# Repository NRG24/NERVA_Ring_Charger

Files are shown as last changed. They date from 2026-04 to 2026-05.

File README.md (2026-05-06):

# NERVA_Ring_Charger
So this is the charger for the NERVA Ring, I suggest taking a look: https://github.com/NRG24/NERVA_Ring This is a portable, magnetic charging case for the ring using a strategic power path management system. There is a 100mAh battery, which balances size with capacity. There are also magnets perfectly spaced to allow for a snapping mechanism. 
The real magic is actually hidden, however. There is an extremely low profile 4mm magnetic pogo connector on the NERVA Ring's PCB that allows for secure connectivity. It was very difficult to find. 
There is a print-in-place hinge for the box to open and close with 0.25mm tolerances. 
The circuit works by splitting the 5V input voltage (USBC) and having one half charge the onboard 100mAh LiPo. Then, it goes through a boost converter to 4.6 volts which is precisely and strategically under 5V. Because of the two Schottky diode OR-ing system, the 5V (top half) current will take priority and go to charge the 22mAh ring battery. When the case is not plugged in, the boost converter will provide just enough voltage and current to charge the ring battery as well.
Screenshot 2026-04-29 at 3 23 45 PM
Screenshot 2026-04-29 at 3 45 39 PM
Screenshot 2026-04-29 at 10 37 57 PM
Screenshot 2026-05-06 at 9 14 18 AM

Screenshot 2026-04-29 at 10 38 20 PM

https://github.com/user-attachments/assets/c79a6dce-659e-46af-84e8-e46c985744b7

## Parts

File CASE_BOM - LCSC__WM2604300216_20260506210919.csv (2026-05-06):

LCSC Part Number | Manufacture Part Number | Manufacturer | Customer NO. | Package | Description | RoHS | Quantity | Unit Price($) | Ext.Price($) | Estimated lead time (business days) | Updated lead time | Date Code / Lot No.
C191023 | 1N5819WS | Guangdong Hottech |  | SOD-323 | Diode 40V 1A Surface Mount SOD-323 | YES | 50 | 0.0111 | 0.56
C424093 | MCP73831T-2ACI/OT | MICROCHIP |  | SOT-23-5 | 3.75V~6V Lithium Battery 1 550mA SOT-23-5 Battery Chargers ICs RoHS | YES | 10 | 0.5988 | 5.99
C7433013 | DY-5173URD/SN-A3(EL)(HF) | TONYU |  | DIP | Red 631nm LED Indication - Discrete 1.8V~2.4V DIP | YES | 10 | 0.0545 | 0.55
C478087 | MCP1640BT-I/CHY | MICROCHIP |  | SOT-23-6 | 500kHz Boost Adjustable 2V~5.5V 350mA SOT-23-6 Voltage Regulators - DC DC Switching Regulators RoHS | YES | 10 | 0.6572 | 6.57
C42400252 | HYCW498-USBC16-735B | HOAUC |  | SMD | USB-C (USB TYPE-C) Receptacle Connector 16 Position Surface Mount, Right Angle | YES | 10 | 0.0481 | 0.48
C1779 | CL21A475KAQNNNE | Samsung Electro-Mechanics |  | 805 | 4.7uF ±10% 25V Ceramic Capacitor X5R 0805 | YES | 20 | 0.0137 | 0.27
C18185759 | TCC0805X5R106M250FT | CCTC |  | 805 | 10uF ±20% 25V Ceramic Capacitor X5R 0805 | YES | 50 | 0.0145 | 0.73
C114862 | LQM18PN4R7MFRL | muRata |  | 603 | 620mA 4.7uH ±20% 550mΩ Multilayer inductor 0603 Fixed Inductors RoHS | YES | 10 | 0.0781 | 0.78
C110775 | RT0805BRD0710KL | YAGEO |  | 805 | 125mW 10kΩ 150V Thin Film Resistor ±25ppm/℃ ±0.1% 0805 Chip Resistor - Surface Mount RoHS | YES | 20 | 0.0336 | 0.67
C104545 | RTT058873FTP | RALEC |  | 805 | 887kΩ ±1% 125mW 0805 Thick Film Resistor | YES | 100 | 0.0021 | 0.21
C410005 | ERJ6ENF3093V | PANASONIC |  | 805 | 125mW 309kΩ Thick Film Resistor ±100ppm/℃ ±1% 0805 Chip Resistor - Surface Mount RoHS | YES | 50 | 0.0087 | 0.44
C131051 | RC0805JR-0747KL | YAGEO |  | 805 | 125mW 47kΩ 150V Thick Film Resistor ±100ppm/℃ ±5% 0805 Chip Resistor - Surface Mount RoHS | YES | 100 | 0.0025 | 0.25
C2907329 | FRC0805J471 TS | FOJAN |  | 805 | 470Ω ±5% 125mW 0805 Thick Film Resistor | YES | 100 | 0.0016 | 0.16
C27834 | 0805W8F5101T5E | UNI-ROYAL |  | 805 | 5.1kΩ ±1% 125mW 0805 Thick Film Resistor | YES | 100 | 0.0027 | 0.27
JLCPCB | PCB |  |  |  |  |  |  |  | 5.48
 |  |  |  |  |  | Parts Total | 28.97
 |  |  |  |  |  | PCB Total | 5.48
 |  |  |  |  |  | Total: | 34.45

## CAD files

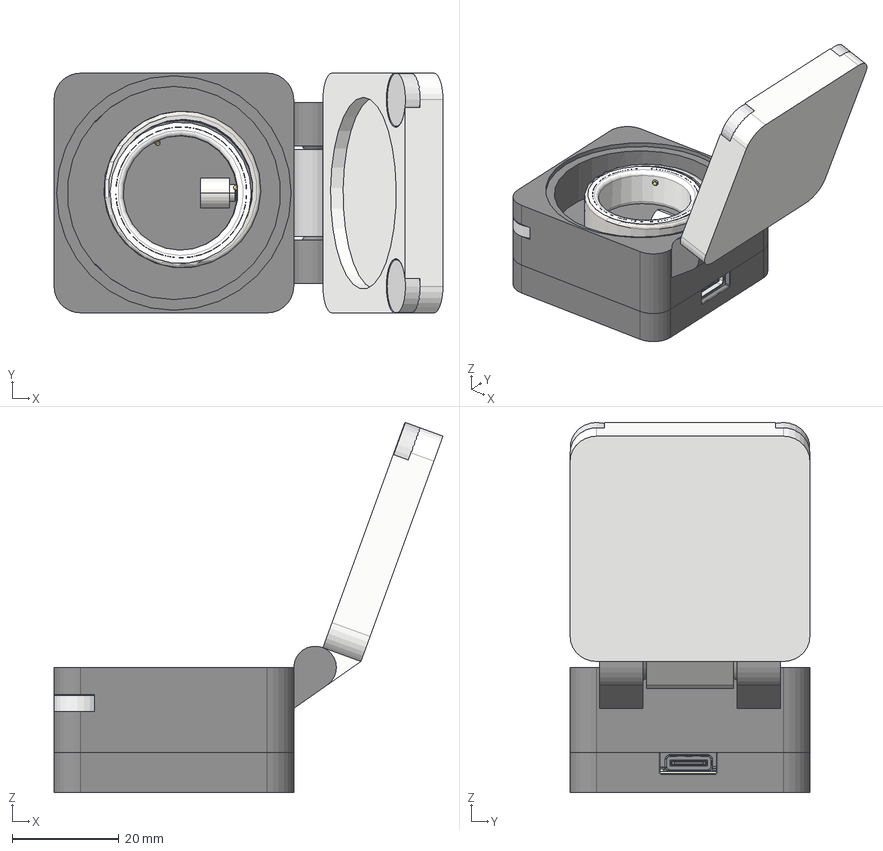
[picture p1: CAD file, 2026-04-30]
CASE_CAD.step
73.0 x 45.0 x 69.5 mm

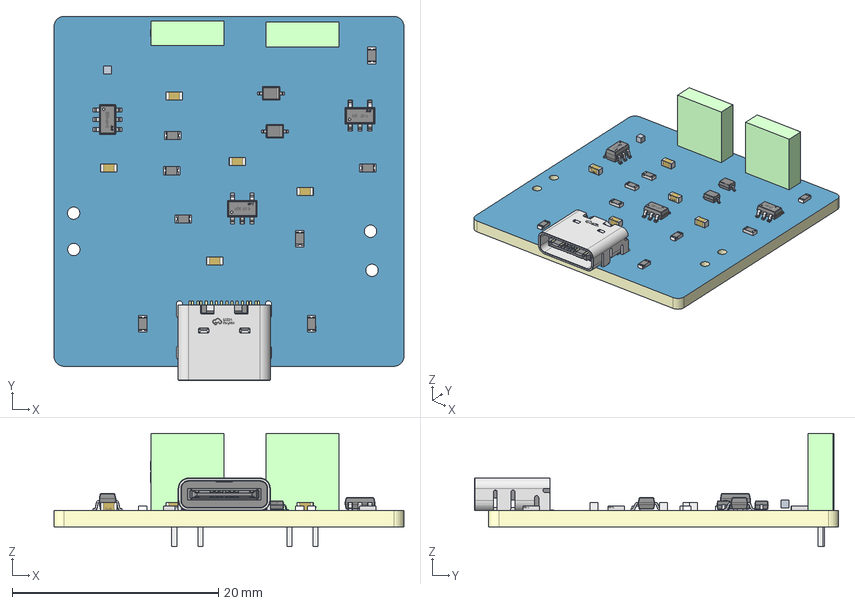
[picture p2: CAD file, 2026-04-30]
3D_PCB1_2026-04-29.step
34.0 x 35.4 x 11.0 mm
Board~A8jz
TopCopper~A8jz
BottomCopper~A8jz
TopFpcStiffener~A8jz
BottomFpcStiffener~A8jz
L0603~L0603_L1.6-W0.8-H0.5_BEAD~A8jz
LED-TH_L7.1-W2.4-FD~LED-TH_L7.1-W2.4-H7.8-P2.54~A8jz x 2
C0805~C0603_L1.6-W0.8-H0.8~A8jz x 5
SOT-23-5_L3.0-W1.7-P0.95-LS2.8-BL~SOT-23-5_ L2.9-W1.6-H1.1-LS2.8-P0.95~A8jz x 2
SOT-23-6_L2.9-W1.6-P0.95-LS2.8-BR~SOT-23-6_ L2.9-W1.6-H1.5-LS2.8-P0.95~A8jz
USB-C-SMD_HYCW498-USBC16-735B~USB-C-SMD_HYCW498-USBC16-735B~A8jz
SOD-323_L1.8-W1.3-LS2.5-RD~SOD-323_L1.8-W1.3-LS2.5-RD~A8jz x 2
R0805~R0603~A8jz x 8

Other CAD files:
Case_CAD.f3d
